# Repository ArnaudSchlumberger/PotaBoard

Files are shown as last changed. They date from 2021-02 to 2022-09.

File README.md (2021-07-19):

# PotaBoard

This repository contains all the code, and PCB design files related to PotaBoard, a BLE-powered board kitchen garden.

It comes with capacitive-moisure sensor and BME280 compatibility for temperature and pressure measurements.

Used microcontroller : ATtiny1604 with Arduino Nano UPDI Programmer

BLE module : EMB1061.

All eletronics-related files are in 'Electronics - Extras' folder, and contains:
- Components Datasheets in 'Datasheets' folder
- Kicad project and related libraries in 'Kicad project' folder

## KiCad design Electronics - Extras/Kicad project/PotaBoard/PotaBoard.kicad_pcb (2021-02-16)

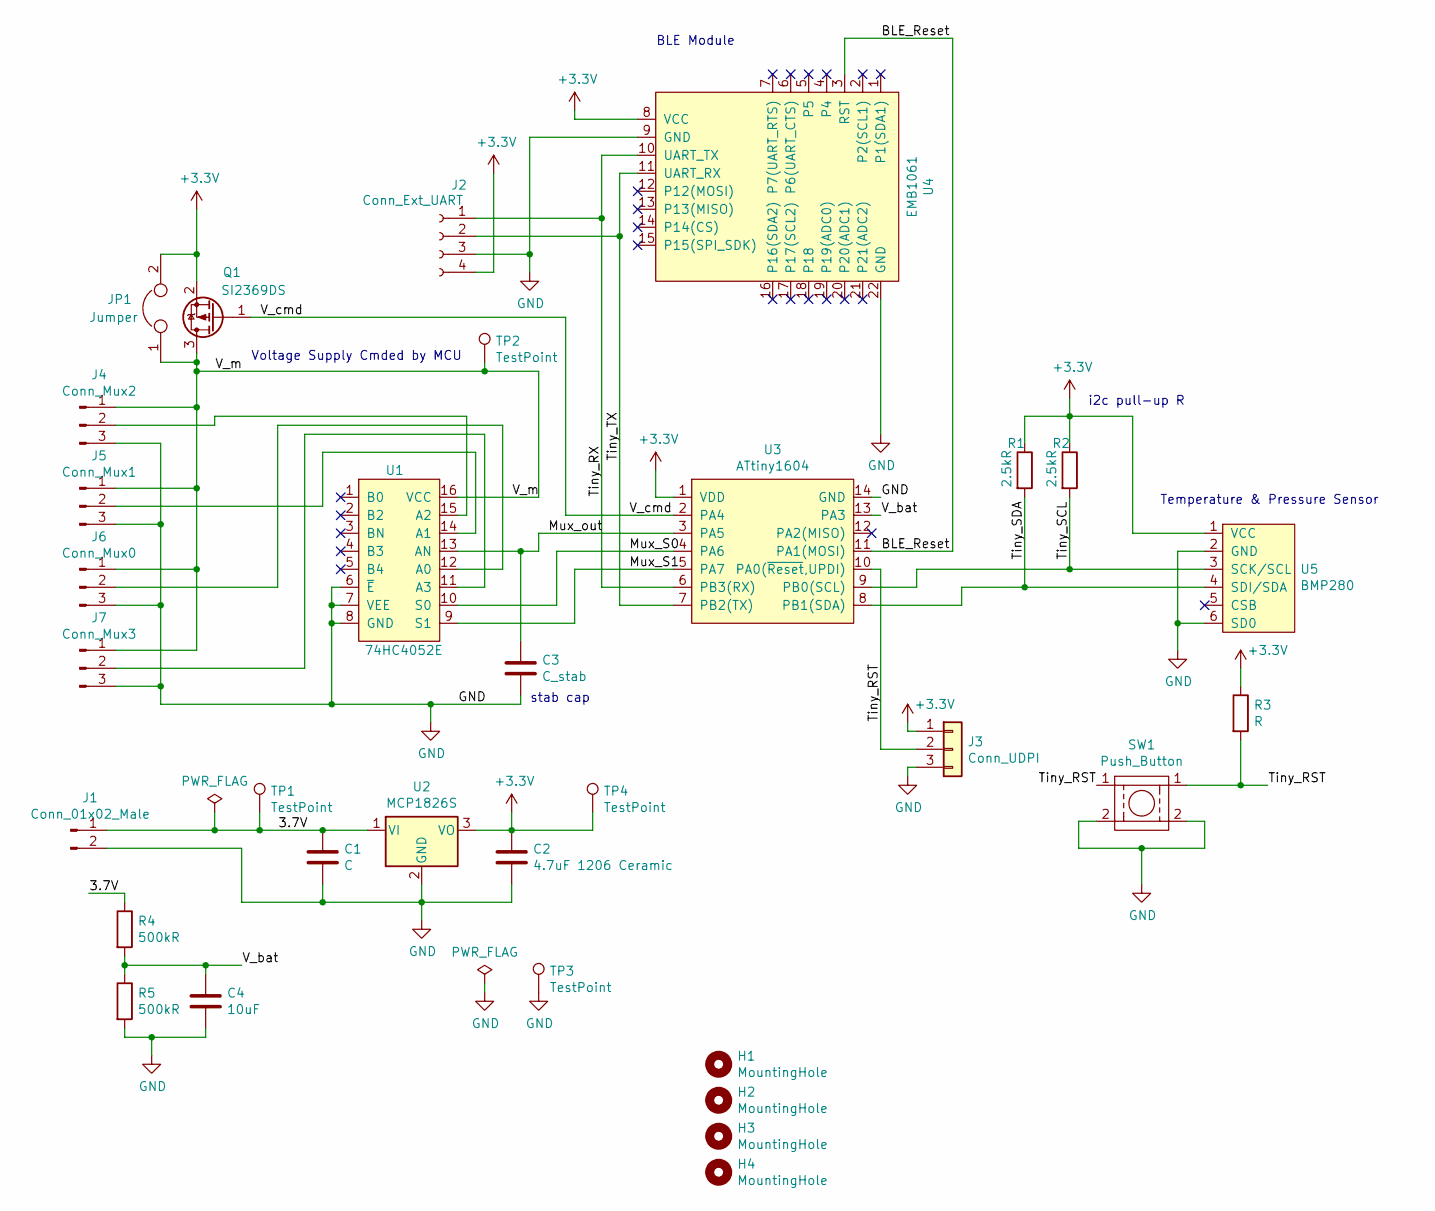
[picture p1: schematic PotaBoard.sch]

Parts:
C1: C; C_1206_3216Metric_Pad1.42x1.75mm_HandSolder
C2: 4.7uF 1206 Ceramic; C_1206_3216Metric_Pad1.42x1.75mm_HandSolder
C3: C_stab; C_1206_3216Metric_Pad1.42x1.75mm_HandSolder
C4: 10uF; C_1206_3216Metric_Pad1.42x1.75mm_HandSolder
H1, H2, H3, H4: MountingHole; MountingHole_3.2mm_M3
J1: Conn_01x02_Male; PinHeader_1x02_P2.54mm_Vertical
J2: Conn_Ext_UART; PinHeader_1x04_P2.54mm_Vertical
J3: Conn_UDPI; PinHeader_1x03_P2.54mm_Vertical
J4: Conn_Mux2; PinHeader_1x03_P2.54mm_Vertical
J5: Conn_Mux1; PinHeader_1x03_P2.54mm_Vertical
J6: Conn_Mux0; PinHeader_1x03_P2.54mm_Vertical
J7: Conn_Mux3; PinHeader_1x03_P2.54mm_Vertical
JP1: Jumper; R_1206_3216Metric_Pad1.42x1.75mm_HandSolder
Q1: SI2369DS; SOT-23_Handsoldering
R1, R2: 2.5kR; R_1206_3216Metric_Pad1.42x1.75mm_HandSolder
R3: R; R_1206_3216Metric_Pad1.42x1.75mm_HandSolder
R4, R5: 500kR; R_1206_3216Metric_Pad1.42x1.75mm_HandSolder
SW1: Push_Button; SW_Push_1P1T_NO_6x6mm_H9.5mm
TP1, TP2, TP3, TP4: TestPoint; TestPoint_Pad_D2.0mm
U1: 74HC4052E; DIP-16_W7.62mm
U2: MCP1826S; SOT-223
U3: ATtiny1604; SOIC-14_3.9x8.7mm_P1.27mm
U4: EMB1061
U5: BMP280

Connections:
+3V3: C2.1, J2.4, J3.1, JP1.2, Q1.2 (S), R1.1, R2.1, R3.1, TP4.1, U2.3 (VO), U3.1 (VDD), U4.8 (VCC), U5.1 (VCC)
/3.7V: C1.1, J1.1, R4.1, TP1.1, U2.1 (VI)
/BLE_Reset: U3.11 (PA1(MOSI)), U4.3 (RST)
/Mux_S0: U1.10 (S0), U3.4 (PA6)
/Mux_S1: U1.9 (S1), U3.5 (PA7)
/Mux_out: C3.1, U1.13 (AN), U3.3 (PA5)
/Tiny_RST: J3.2, R3.2, SW1.1, U3.10 (PA0(~Reset~,UPDI))
/Tiny_RX: J2.1, U3.6 (PB3(RX)), U4.10 (UART_TX)
/Tiny_SCL: R2.2, U3.9 (PB0(SCL)), U5.3 (SCK/SCL)
/Tiny_SDA: R1.2, U3.8 (PB1(SDA)), U5.4 (SDI/SDA)
/Tiny_TX: J2.2, U3.7 (PB2(TX)), U4.11 (UART_RX)
/V_bat: C4.1, R4.2, R5.1, U3.13 (PA3)
/V_cmd: Q1.1 (G), U3.2 (PA4)
/V_m: J4.1, J5.1, J6.1, J7.1, JP1.1, Q1.3 (D), TP2.1, U1.16 (VCC)
GND: C1.2, C2.2, C3.2, C4.2, J1.2, J2.3, J3.3, J4.3, J5.3, J6.3, J7.3, R5.2, SW1.2, TP3.1, U1.6 (~E), U1.7 (VEE), U1.8 (GND), U2.2 (GND), U3.14 (GND), U4.9 (GND), U4.22 (GND), U5.2 (GND), U5.6 (SD0)
unnamed: J4.2, U1.15 (A2)
unnamed: J5.2, U1.14 (A1)
unnamed: J6.2, U1.12 (A0)
unnamed: J7.2, U1.11 (A3)

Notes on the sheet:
i2c pull-up R
stab cap
Voltage Supply Cmded by MCU
Temperature & Pressure Sensor
BLE Module

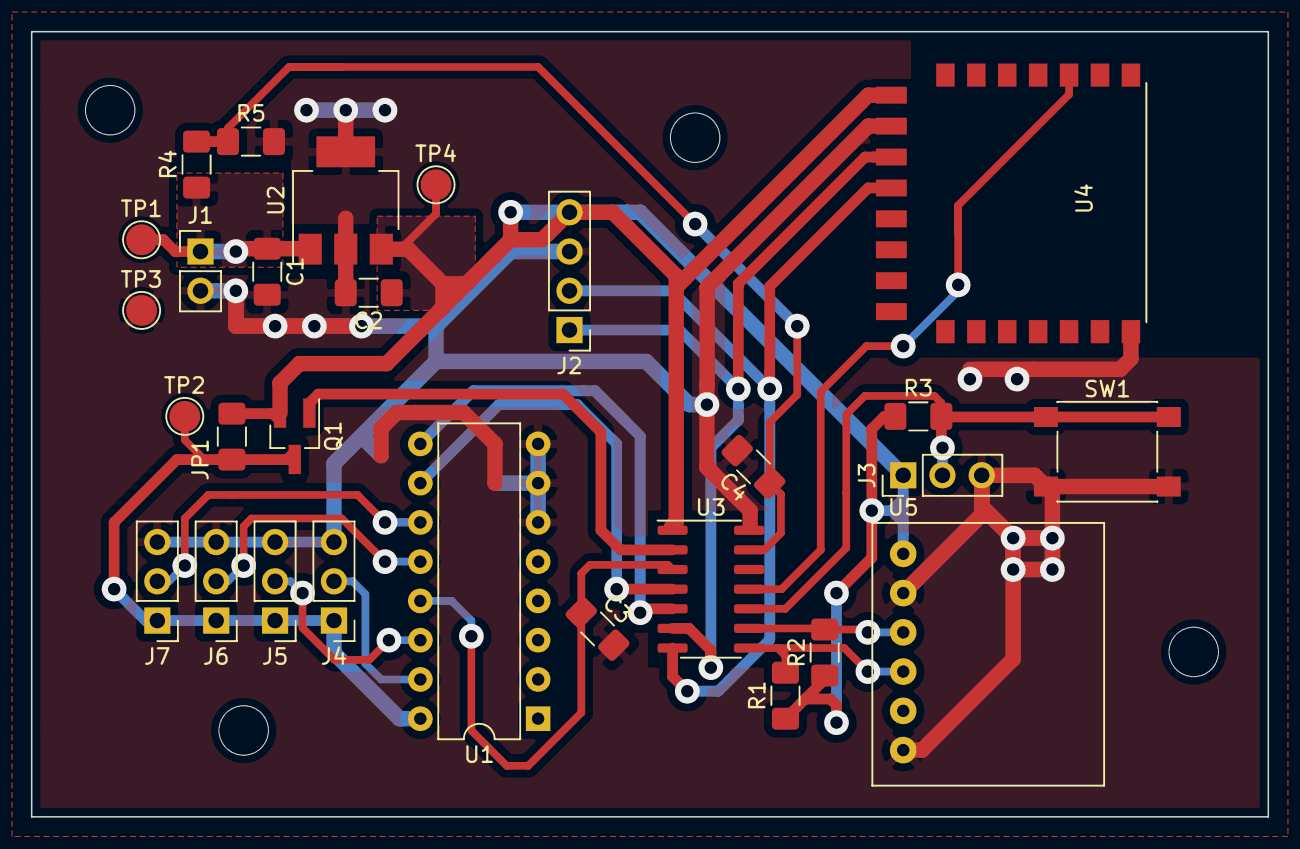
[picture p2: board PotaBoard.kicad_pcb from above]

Board: 2 copper layers, 80.0 x 50.8 mm, 32 parts (0 on the bottom side), 19 nets.

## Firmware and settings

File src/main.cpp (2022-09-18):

#include <Arduino.h>
//#include <megaTinyCore.h>
#include <Wire.h>
#include "Adafruit_BMP280.h"

#include "keywords.h"
#include "pins.h"

#include "mux.h"
#include "battery.h"
#include "sleep.h"
#include "BME.h"
#include "PotaData.h"

#include "clock_management.h"

#define _DEBUG_MODE

#define DELAY_BEFORE_SLEEP 50 //ms; delay at end of loop
#define EMB1061_TRANSPARENT_DELAY 1000 // ms; delay allowing BLE to leave Boot Mode and enter Transparent Mode
float temperature;
float pression;
uint16_t h1,h2,h3,h4; //humidity
bool bmp_ok;


Adafruit_BMP280 bmp;

void setup() {

  Serial.begin(7680); //9600 adjusted baud (for this chip, clock freq is multiplied by 1.25)
  delay(100);
  //Uncomment next paragraph to configure BLE Module
  /* 
  Serial.print("**\r");
  Serial.print("AT+BNAME=POTABOARD\r");
  delay(2000);
  Serial.print("AT+UARTCFG=9600,8,0,1,0\r");
  delay(2000);
  Serial.print("AT+SAVE\r");
  Serial.print("AT+REBOOT\r");
  */
  delay(EMB1061_TRANSPARENT_DELAY); //Waits for BLE Module to enter Transparent Mode (UART Direct Transmission Mode)

  Wire.begin();
  bmp_ok = bmp.begin(BME280_ADDR,BME280_ID_VALUE);
  bmp.setSampling(Adafruit_BMP280::MODE_FORCED,
                  Adafruit_BMP280::SAMPLING_X4,
                  Adafruit_BMP280::SAMPLING_X4,
                  Adafruit_BMP280::FILTER_X2,      
                  Adafruit_BMP280::STANDBY_MS_500);
  sleepConfig();
  pinMode(V_bat, INPUT);
}

void loop(){
  while(Serial.available()>0 and bmp_ok){
    if((Serial.peek())==0xC0){
      Serial.read();
      collectDataTempPress(bmp, temperature,pression);
    }
    if((Serial.peek())==0xC2){
      Serial.read();
      Serial.print(temperature);
    }
    if((Serial.peek())==0xC4){
      Serial.read();
      Serial.print(pression);
    }
    else if(Serial.peek()==0xE0){
      Serial.read();
      collectDataHumidity(h1, h2, h3, h4);
    }
    else if(Serial.peek()==0xE1){
      Serial.read();
      Serial.print(h1);
    }
    else if(Serial.peek()==0xE2){
      Serial.read();
      Serial.print(h2);
    }
    else if(Serial.peek()==0xE3){
      Serial.read();
      Serial.print(h3);
    }
    else if(Serial.peek()==0xE4){
      Serial.read();
      Serial.print(h4);
    }
    else if(Serial.peek()==0x0B){
      Serial.read();
      sendBatteryVoltage(readBattVoltage());
    }

    #ifdef DEBUG_MODE
    else{
        Serial.write(Serial.read()); //Repeats received value for debugging purposes
    }
    #endif
  }
  if(!bmp_ok){
    Serial.write("BMP ERR");
  }
  delay(DELAY_BEFORE_SLEEP);
  sleep();
  delay(500); //Wake-up delay
}

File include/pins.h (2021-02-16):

#ifndef PINS_H
#define PINS_H

#define V_CMD 0 //Output pin to control multiplexer power supply
#define MUX_OUT 1 //Analog input for Mux value reading
#define MUX_SEL_0 2 //Digital output to Mux S0 pin
#define MUX_SEL_1 3 //Digital output to Mux S1 pin
#define BLE_Reset 8 //Digital output to BLE Reset pin
#define V_bat 10 //Analog input to battery voltage (divided by a factor 2)


#endif

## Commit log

2021-02-16 Added references related to PCB design and electronics
    [EMB_footprintTest.kicad_pcb, EMB_footprintTest.sch, PotaBoard.kicad_pcb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]
2021-07-19 Retrait fonctionnalite DUTY CYCLE sur les DI - Mise a jour valeur de resistance AOx
2022-09-18 Battery : modified voltage reading function, added raw ADC reading function. Main : added debug mode, cleaned unused variables, reforged BLE instructions values and overall working principle. Potadat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
